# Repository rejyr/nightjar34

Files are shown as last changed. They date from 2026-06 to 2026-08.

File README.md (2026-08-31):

# nightjar34

docs WIP

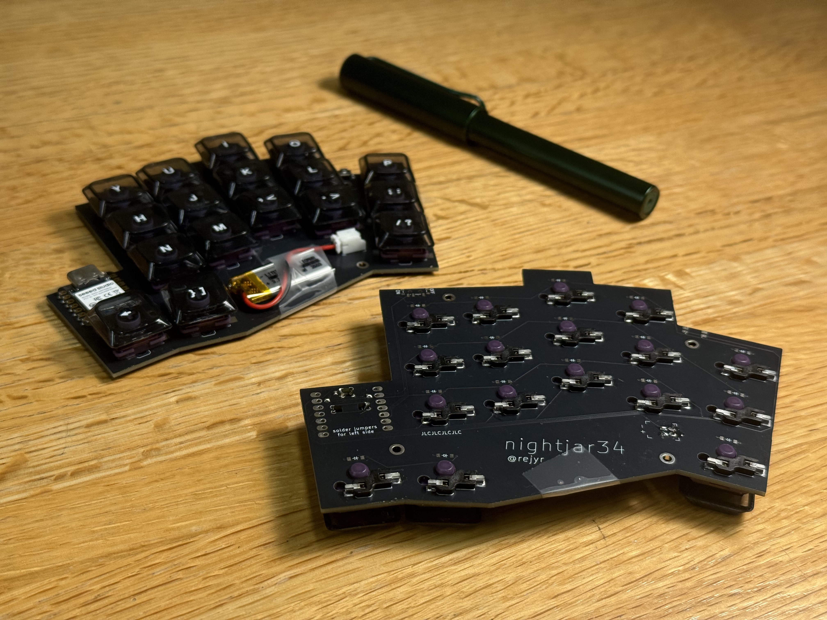
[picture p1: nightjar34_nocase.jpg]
nightjar34 keyboard without a case

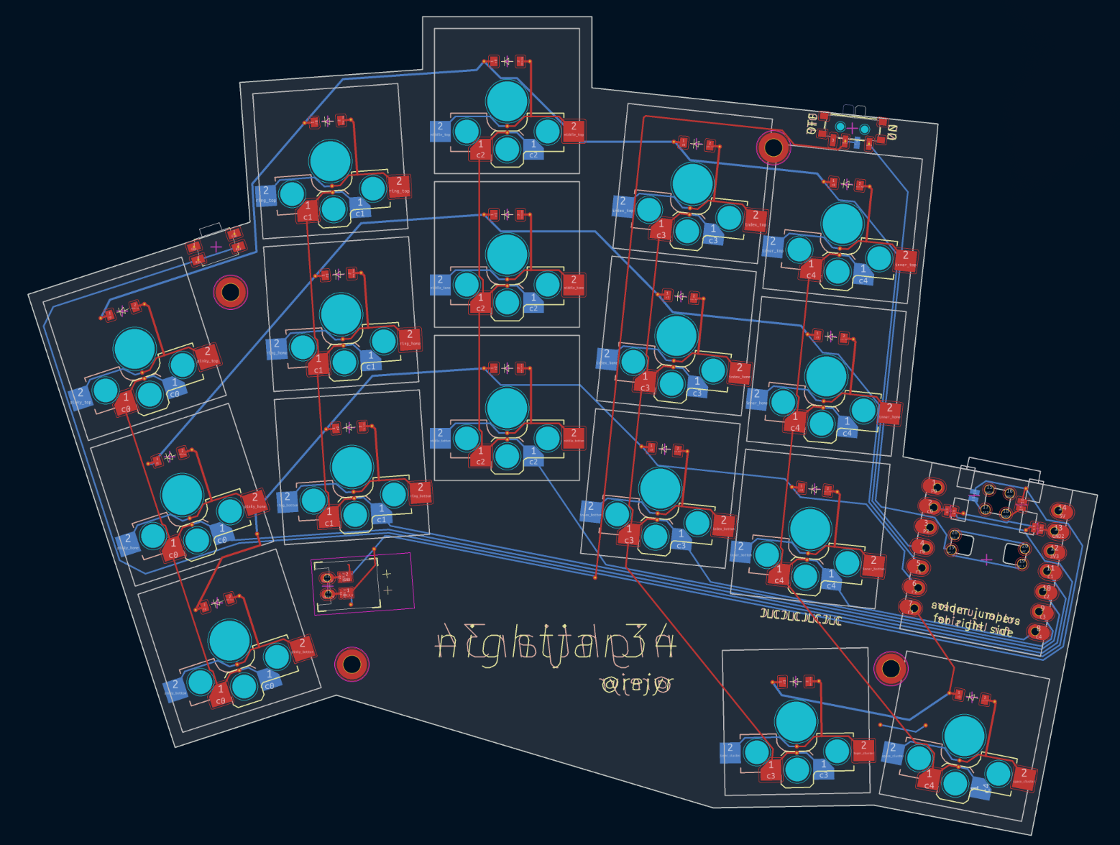
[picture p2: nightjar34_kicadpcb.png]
nightjar34 pcb view from KiCAD


# pcb
## connecting kicad traces
set `File > Board Setup... > Design Rules > Constraints > Copper to edge clearance:` to `0.25` mm

this removes the `The routing start point violates DRC.` error when routing the xiao ble underside pins

# references
- [TOTEM keyboard](https://github.com/GEIGEIGEIST/TOTEM)
- [Architeuthis dux keyboard](https://github.com/tapioki/cephalopoda/tree/main/Architeuthis%20dux)
- [kiai keyboard](https://github.com/makgyber/kiai-split/tree/main)
- [xiao ble resources](https://wiki.seeedstudio.com/XIAO_BLE/#resources)
- [choc v2 switches guide](https://showcase.beekeeb.com/kailh-choc-v2-key-switches/)
- [choc v2 keycaps guide](https://showcase.beekeeb.com/choc-spaced-chocv2-keycaps/)
- [ergogen](https://ergogen.xyz/)
- [FlatFootFox ergogen guide](https://flatfootfox.com/ergogen-introduction/)
- [convert kicad footprints to ergogen](https://nilnil.notion.site/Convert-Kicad-Footprints-to-Ergogen-8340ce87ad554c69af4e3f92bc9a0898)
- [ceoloide ergogen footprints](https://github.com/ceoloide/ergogen-footprints)
- [ergogen v4 footprints](https://github.com/ImStuBTW/ergogen-v4-footprints)
- [CERN OHL v2 license](https://gitlab.com/ohwr/project/cernohl/-/wikis/Documents/CERN-OHL-version-2)
- [nightjar bird](https://en.wikipedia.org/wiki/Nightjar)

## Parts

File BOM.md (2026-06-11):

# part list
| name | quantity | description | sources |
| --- | --- | --- | --- |
| nightjar34 pcb | 2 | | |
| xiao ble | 2 | | [(seeed studio)](https://www.seeedstudio.com/Seeed-XIAO-BLE-nRF52840-p-5201.html); [(amazon)](https://www.amazon.com/Seeed-Studio-XIAO-nRF52840-Microcontroller/dp/B09T9VVQG7) |
| diode | 34 | 1N4148W SOD-123 | [(typeractive)](https://typeractive.xyz/products/smd-diodes?variant=45597514858727) |
| hotswap socket | 34 | kalih choc | [(typeractive)](https://typeractive.xyz/products/hotswap-sockets?variant=45742200324327) |
| power switch | 2 | alps SSSS811101 | [(typeractive)](https://typeractive.xyz/products/power-switch) |
| reset switch | 2 | panasonic EVQ-PU\[A\|C\|J\|L\]02K | [(typeractive)](https://typeractive.xyz/products/reset-button) |
| lithium battery | 2 | 3.7v 110mAh 301230, WHT PH 2.0mm | [(typeractive)](https://typeractive.xyz/products/lithium-battery-110mah?variant=43294731665639) |
| battery jack | 2 | JST PH 2.0mm | [(typeractive)](https://typeractive.xyz/products/battery-jack) |
| key switch | 34 | choc v2 | [kalih purple iris silent (amazon)](https://www.amazon.com/YMDK-Profile-Switches-Actuation-Keyboards/dp/B0GHRN82Z5) |
| keycap | 34 | low profile, mx stem, mx spacing (choc v2) | [ymdk (amazon)](https://www.amazon.com/YMDK-Ultra-Slim-Profile-Mechanical-Keyboard/dp/B0DPQHHF2Z) |

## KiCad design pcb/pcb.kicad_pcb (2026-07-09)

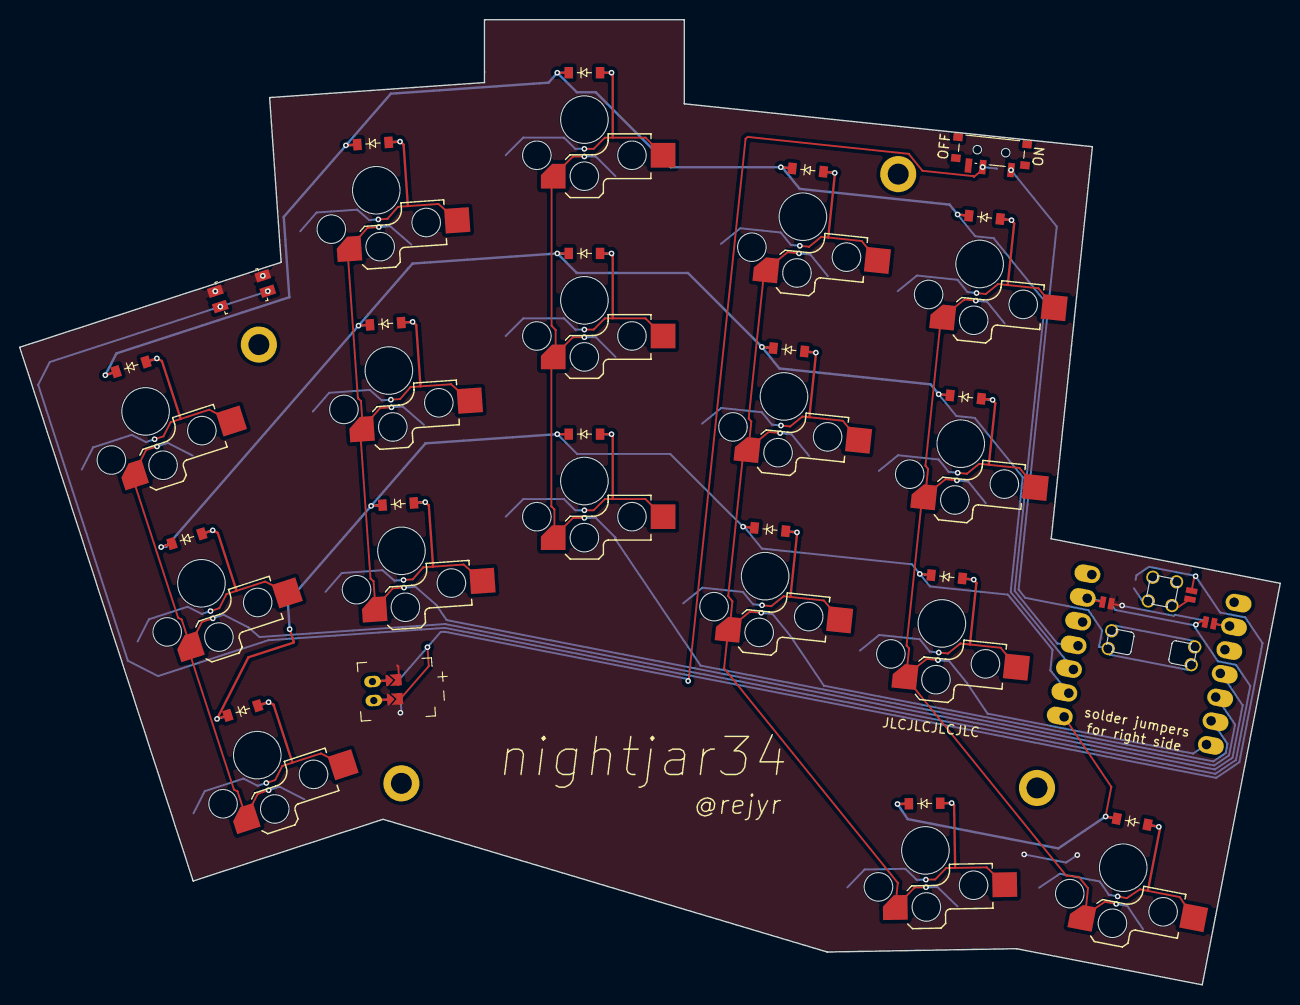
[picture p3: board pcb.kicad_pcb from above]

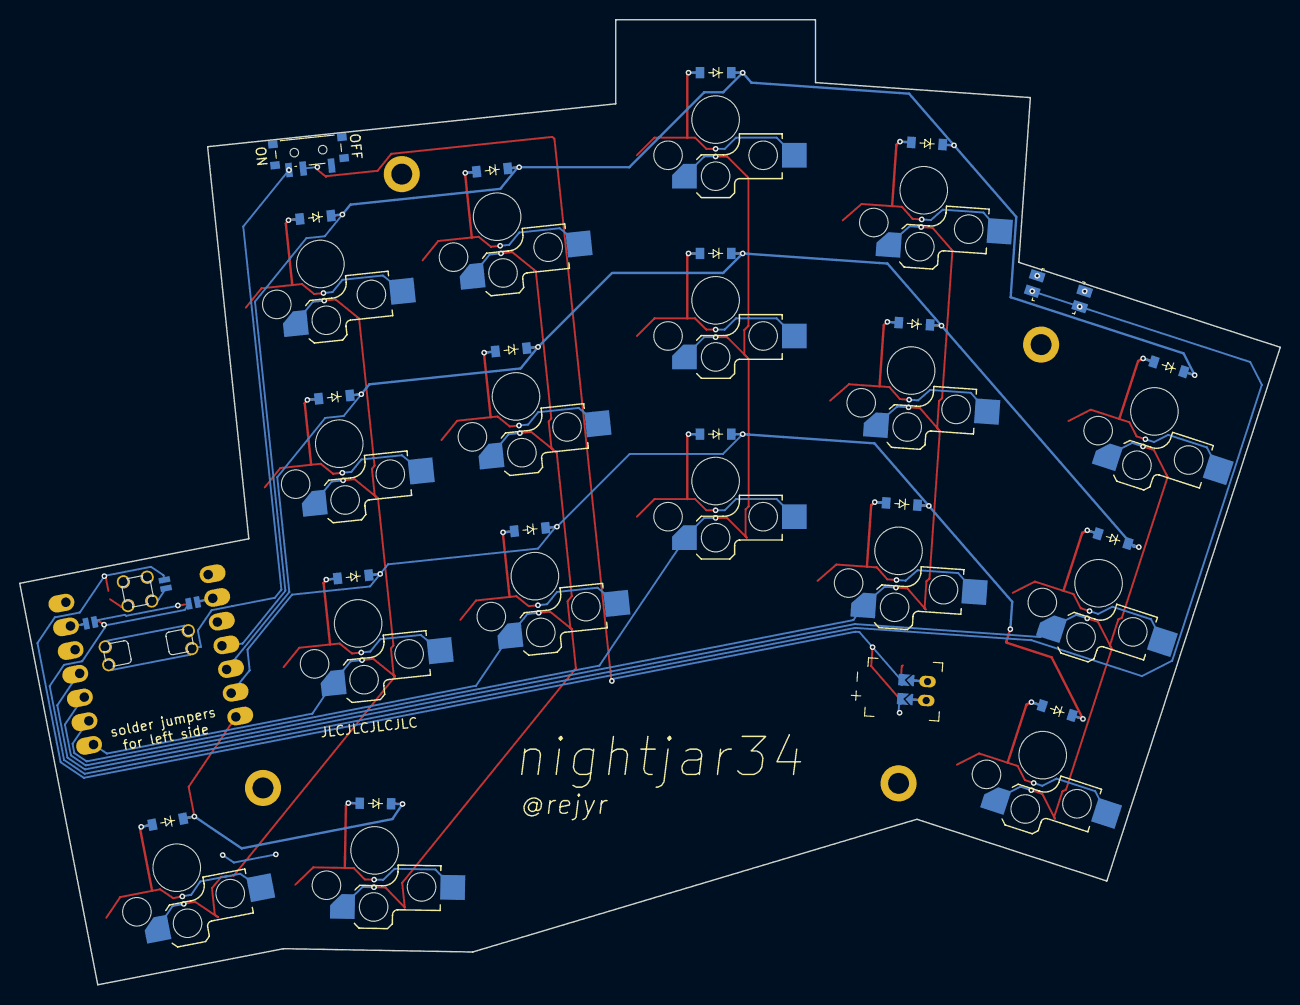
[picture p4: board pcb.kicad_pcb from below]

Board: 2 copper layers, 132.5 x 101.5 mm, 46 parts (18 on the bottom side), 33 nets.

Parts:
D1, D2, D3, D4, D5, D6, D7, D8, D9, D10, D11, D12, D13, D14, D15, D16, D17: diode_tht_sod123
H1, H2, H3, H4: mounting_hole_plated
JST1: battery_connector_jst_ph_2
MCU1: mcu_xiao_ble
PWR1: power_switch_smd_side
RST1: reset_switch_smd_side
S1, S2, S3, S4, S5, S6, S7, S8, S9, S10, S11, S12, S13, S14, S15, S16, S17: switch_choc_v1_v2
_1, _2, _3, _4: jumper

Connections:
BAT_P_1: MCU1.19, PWR1.1, PWR1.3
BAT_P_2: JST1.1, PWR1.2
GND: JST1.2, RST1.1, RST1.3, _1.12, _2.22
GND2: MCU1.13, MCU1.18, _2.11, _2.21, _4.11
JST1_1: JST1.11, JST1.21, JST1.31
JST1_2: JST1.12, JST1.22, JST1.32
RST: MCU1.17, RST1.2, RST1.4, _3.11, _3.12, _4.12
c0: MCU1.2, S1.1, S2.1, S3.1, _1.11, _1.21, _1.22, _2.12
c1: MCU1.11, S4.1, S5.1, S6.1
c2: MCU1.10, S7.1, S8.1, S9.1
c3: MCU1.9, S10.1, S11.1, S12.1, S16.1
c4: MCU1.8, S13.1, S14.1, S15.1, S17.1
index_bottom: D10.2, S10.2
index_home: D11.2, S11.2
index_top: D12.2, S12.2
inner_bottom: D13.2, S13.2
inner_home: D14.2, S14.2
inner_top: D15.2, S15.2
layer_cluster: D16.2, S16.2
middle_bottom: D7.2, S7.2
middle_home: D8.2, S8.2
middle_top: D9.2, S9.2
pinky_bottom: D1.2, S1.2
pinky_home: D2.2, S2.2
pinky_top: D3.2, S3.2
r0: D3.1, D6.1, D9.1, D12.1, D15.1, MCU1.4
r1: D2.1, D5.1, D8.1, D11.1, D14.1, MCU1.5
r2: D1.1, D4.1, D7.1, D10.1, D13.1, MCU1.6
r3: D16.1, D17.1, MCU1.7
ring_bottom: D4.2, S4.2
ring_home: D5.2, S5.2
ring_top: D6.2, S6.2
space_cluster: D17.2, S17.2

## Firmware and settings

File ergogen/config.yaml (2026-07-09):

meta:
  engine: 4.1.0
units:
  kx: u
  ky: u
  px: kx + 2
  py: ky + 2
  cx: 18
  cy: 18
points:
  zones:
    matrix:
      anchor.shift: [100,-150]
      key: 
        padding: 1ky
        spread: 1kx
      columns:
        pinky: 
          key:
            stagger: 0
            splay: 18
            column_net: c0
        ring:
          key:
            stagger: 16
            splay: -14
            origin: [0,-8.5]
            column_net: c1
        middle:
          key:
            stagger: 6
            splay: -4
            origin: [0,-10]
            column_net: c2
        index:
          key:
            stagger: -10
            splay: -6
            origin: [0,-0]
            column_net: c3
        inner:
          key:
            stagger: -3
            column_net: c4
      rows:
        bottom:
          row_net: r2
        home:
          row_net: r1
        top:
          row_net: r0
    thumbs:
      anchor:
        ref: matrix_inner_bottom
        shift: [-0kx+2, -ky-6]
      key:
        padding: 1ky
        spread: 1kx
        origin: [-kx/2, -ky/2]
      columns:
        layer:
          key:
            splay: 7
            column_net: c3
        space:
          key:
            splay: -12
            column_net: c4
      rows:
        cluster:
          row_net: r3
outlines:
  keys:
    - what: rectangle
      where: true
      size: [kx - 0.5, ky - 0.5]
  board:
    - what: rectangle
      where: true
      size: [px,py]
      # connect thumbs
    - what: rectangle
      where: matrix_inner_bottom
      size: [1px,0.6py]
      adjust.shift: [0.0px,-0.5py]
    - what: rectangle
      where: thumbs_layer_cluster
      size: [1px,2py]
      adjust.shift: [0px,0.5py]
    - what: rectangle
      where: thumbs_space_cluster
      size: [1.5px,1py]
      adjust.shift: [-0.25px,0py]
      # close gap between pinky and ring
    - what: rectangle
      where: matrix_pinky_top
      size: [1.5px,1.6py]
      adjust.shift: [0.5px,-0.3py]
      # close gap between ring and middle
    - what: rectangle
      where: matrix_ring_top
      size: [1.5px,2py]
      adjust.shift: [0.5px,-0.5py]
      # close gap between middle and index
    - what: rectangle
      where: matrix_index_top
      size: [1.5px,2py]
      adjust.shift: [-0.5px,-0.5py]
      # space for button over inner column
    - what: rectangle
      where: matrix_index_top
      size: [2kx,1py]
      adjust.shift: [0.5px,0py]
      # close palm gap
    - what: polygon
      operation: add
      points:
        - ref: matrix_pinky_bottom
          shift: [0.5px,-0.5py]
        - ref: thumbs_layer_cluster
          shift: [-0.5px,-0.5py]
        - ref: matrix_index_home
          shift: [0.5px,0.5py]
        - ref: matrix_pinky_home
          shift: [0.5px,0.5py]
    # - what: rectangle
    #   where: [matrix_pinky_bottom]
    #   size: [4px,2py]
    #   adjust.shift: [1.5px,0.5py]
      # mcu spot
    - what: rectangle
      where: thumbs_space_cluster
      size: [1.0px+4,1.0py+2]
      adjust.shift: [0px-2,1py]
  combo:
    - name: board
    - operation: subtract
      name: keys
pcbs:
  pcb:
    template: kicad8
    outlines.main.outline: board
    footprints:
      mcu:
        what: mcu_xiao_ble
        where:
          ref: thumbs_space_cluster
          shift: [0kx-1.5,1ky+3]
          rotate: 0
        params:
          side: "F"
          reversible: true
          enable_nfc: false

          GND: GND2
          BAT_P: BAT_P_1

          P1: c0

          P3: r0
          P4: r1
          P5: r2
          P6: r3
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

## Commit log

2026-06-09 feat: bill of materials
2026-06-09 fix(bom): unescaped pipe in md table
2026-06-09 feat(ergogen): add row and column nets
    TODO: fix mcu_xiao_ble footprint so reversble pads are not stacked and
    conflicting.
    [config.yaml]
2026-06-10 feat(README): kicad traces note
2026-06-10 feat(bom): description column and header tweak
2026-06-10 feat: remove old board outline
2026-06-11 feat(ergogen): place mcu and switches
2026-06-11 refactor(ergogen): remove unnecessary brackets and comments
2026-06-11 feat(ergogen): place battery connector
2026-06-11 feat(ergogen): jumper pad footprint
2026-06-11 feat(ergogen): enable_nfc for mcu_xiao_ble footprint
2026-06-11 feat(jumper_pad.js): hardcode pin numbers
2026-06-12 feat(ergogen): power switch pins
2026-06-12 feat(ergogen): flavor silkscreen
2026-06-12 feat(ergogen): mounting holes
2026-06-12 feat(ergogen): ground filled zone
2026-06-12 feat(ergogen): avoid ground zone fill to flippable pads
    [config.yaml]
2026-06-12 feat(ergogen): adjust column pin assignments
2026-06-12 feat(pcb): upload pcb
    [pcb.kicad_pcb]
2026-06-12 feat(gerbers): upload gerbers
    [pcb-B_Cu.gbr, pcb-B_Mask.gbr, pcb-B_Paste.gbr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]
2026-07-09 fix: flipped underside RST/GND
    [pcb-B_Cu.gbr, pcb-B_Mask.gbr, pcb-B_Paste.gbr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]
